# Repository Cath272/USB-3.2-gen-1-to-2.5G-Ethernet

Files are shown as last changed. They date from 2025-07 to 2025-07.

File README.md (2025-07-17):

# USB 3.2 gen 1 to 2.5Gb Ethernet
 2.5GbE to USB C using VL162 and RTL8156

 ## VL162

  - 4:2 10Gbps USB Type-C Data Switch

  - Low power consumption with 6mW active at device mode

 ## RTL8156BG 

  - Integrated 10/100/1000M/2.5G transceiver

  - Supports USB 3.0, 2.0, and 1.1

 ## TPS62420

 - 5V to 3.3V DC-DC (600mA)
 - 5V to 0.95V DC-DC (1A)

 ## W25Q16BVSSIG

 - 16Mbit SPI Flash  

 ## LX82405SP
 -2.5GbE Magnetics 
## PCB 
This board uses a 4 layer stackup with a  1.6mm thickness:

- POWER/SIGNAL

- GND
  
- GND
  
- POWER/SIGNAL

High Speed diferential lines need a refrence ground plane so internal planes are ground referance planes for the High speed USB lines

### Schematic:
Schematic
## PCB Screenshots

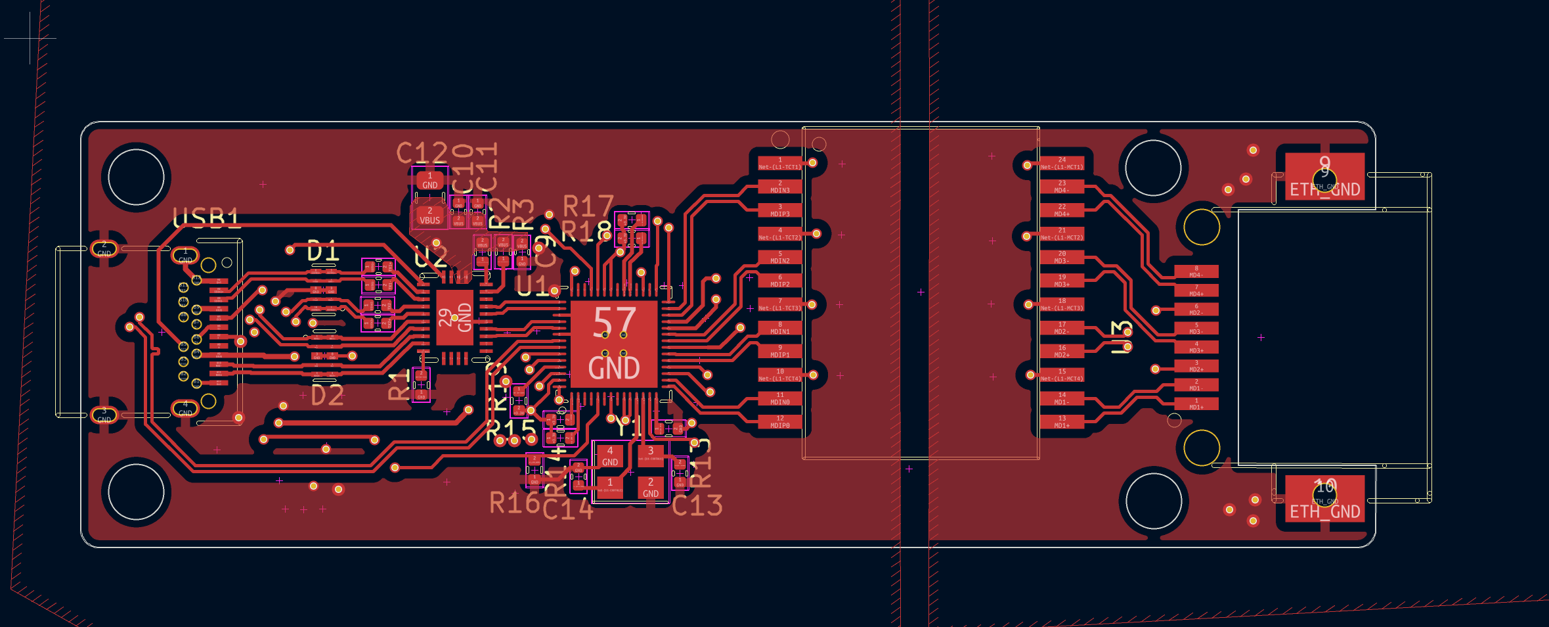
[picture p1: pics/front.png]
usb3ethfront

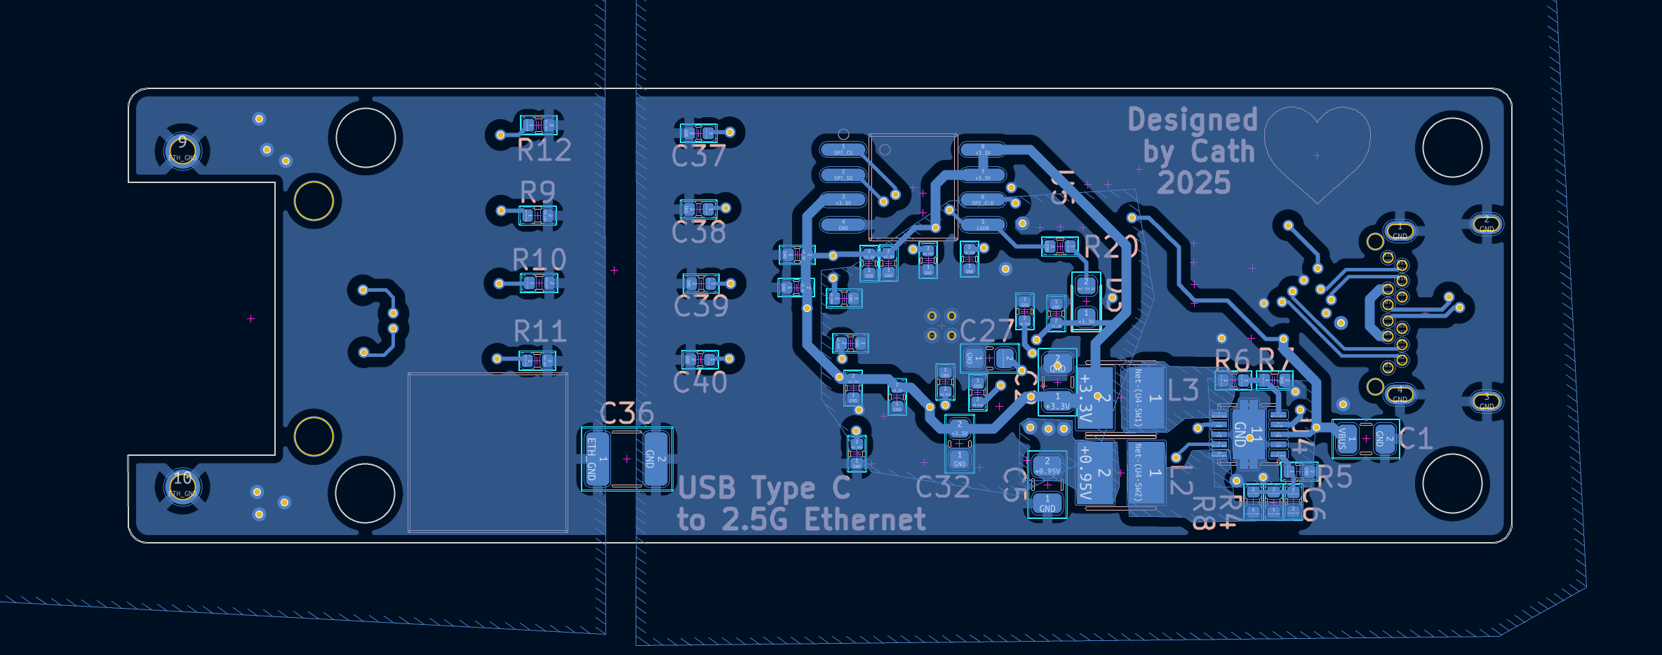
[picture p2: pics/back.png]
usb3ethback

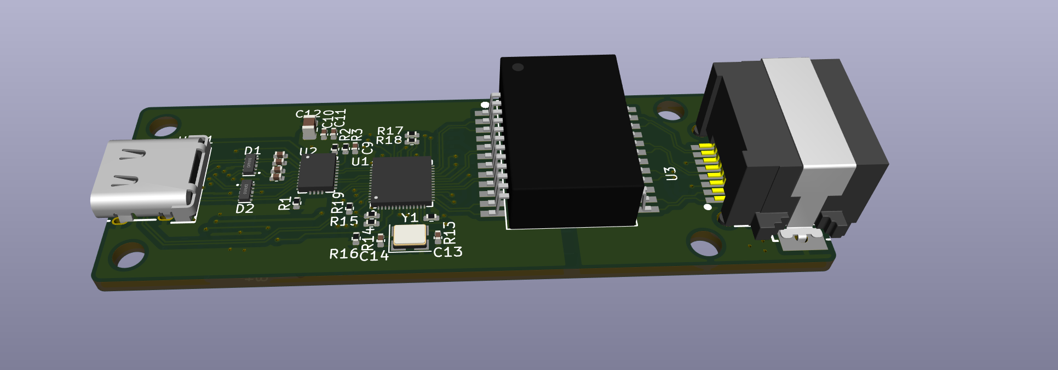
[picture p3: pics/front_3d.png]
usb3ethfront3d

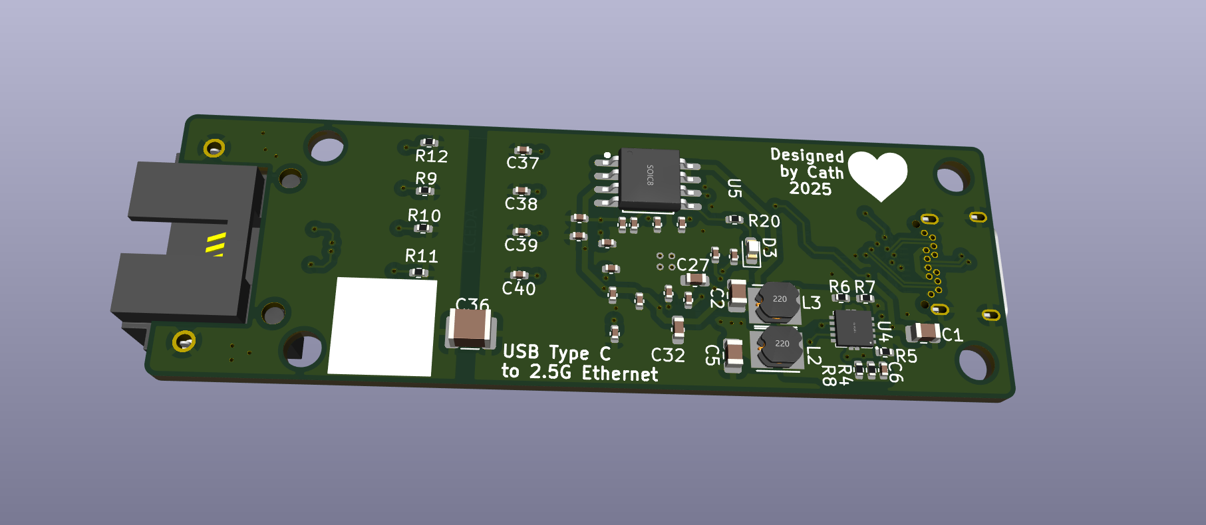
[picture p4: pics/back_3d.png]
usb3ethback3d


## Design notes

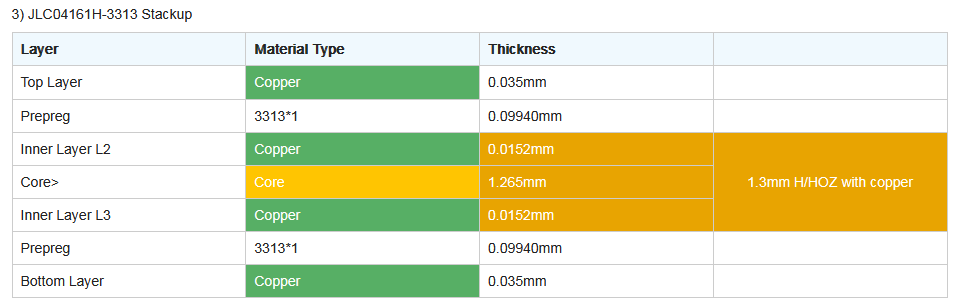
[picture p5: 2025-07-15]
Stackup.png

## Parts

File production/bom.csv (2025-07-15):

Designator | Footprint | Quantity | Value | LCSC Part #
C1, C12 | 0805 | 2 | 10uF
C10, C11, C16, C17, C18, C19, C20, C21, C22, C23, C24, C25, C26, C28, C29, C3, C30, C31, C37, C38, C39, C4, C40, C7, C8, C9 | 0402 | 26 | 100nF
C13, C14 | 0402 | 2 | 18pF
C2, C5 | 0805 | 2 | 22uF
C27, C32 | 0603 | 2 | 1uF
C36 | 1210 | 1 | 1nF 2kV
C6 | 0402 | 1 | 33pF
D1, D2 | DFN-10L_L2.5-W1.0-P0.50-BL | 2 | RCLAMP0524P-N | C316044
D3 | 0603 | 1 | LED
L1 | XFMR-SMD_HY602401 | 1 | HY602401 | C55685
L2, L3 | IND-SMD_L3.5-W3.0 | 2 | 2.2uH
R1 | 0402 | 1 | 124k
R10, R11, R12, R9 | 0402 | 4 | 75R
R13 | 0402 | 1 | 2.49K
R14, R15, R16, R17, R18, R19 | 0402 | 6 | 4.7K
R2, R3 | 0402 | 2 | 10k
R20 | 0402 | 1 | 220R
R4, R7 | 0402 | 2 | 180k
R5 | 0402 | 1 | 280k
R6 | 0402 | 1 | 910k
R8 | 0402 | 1 | 1.8M
U1 | QFN-56_L6.0-W6.0-P0.35--TL-EP4.7 | 1 | RTL8156BG-CG | C41376388
U2 | MQFN-28_L4.5-W3.5-P0.40-BL-EP | 1 | VL162 | C19270896
U3 | RJ45-SMD_HC-RJ45-055-7_1 | 1 | HC-RJ45-055-7 | C3000213
U4 | VSON-10_L3.0-W3.0-P0.50-TL-EP | 1 | TPS62420DRCR | C74233
U5 | SOIC-8_L5.3-W5.3-P1.27-LS8.0-BL | 1 | W25Q16BVSSIG
USB1 | USB-C-SMD_TYPEC-324-BCP24 | 1 | TYPEC-324-BCP24 | C2835314
Y1 | Crystal_SMD_3225-4Pin_3.2x2.5mm | 1 | 25Mhz

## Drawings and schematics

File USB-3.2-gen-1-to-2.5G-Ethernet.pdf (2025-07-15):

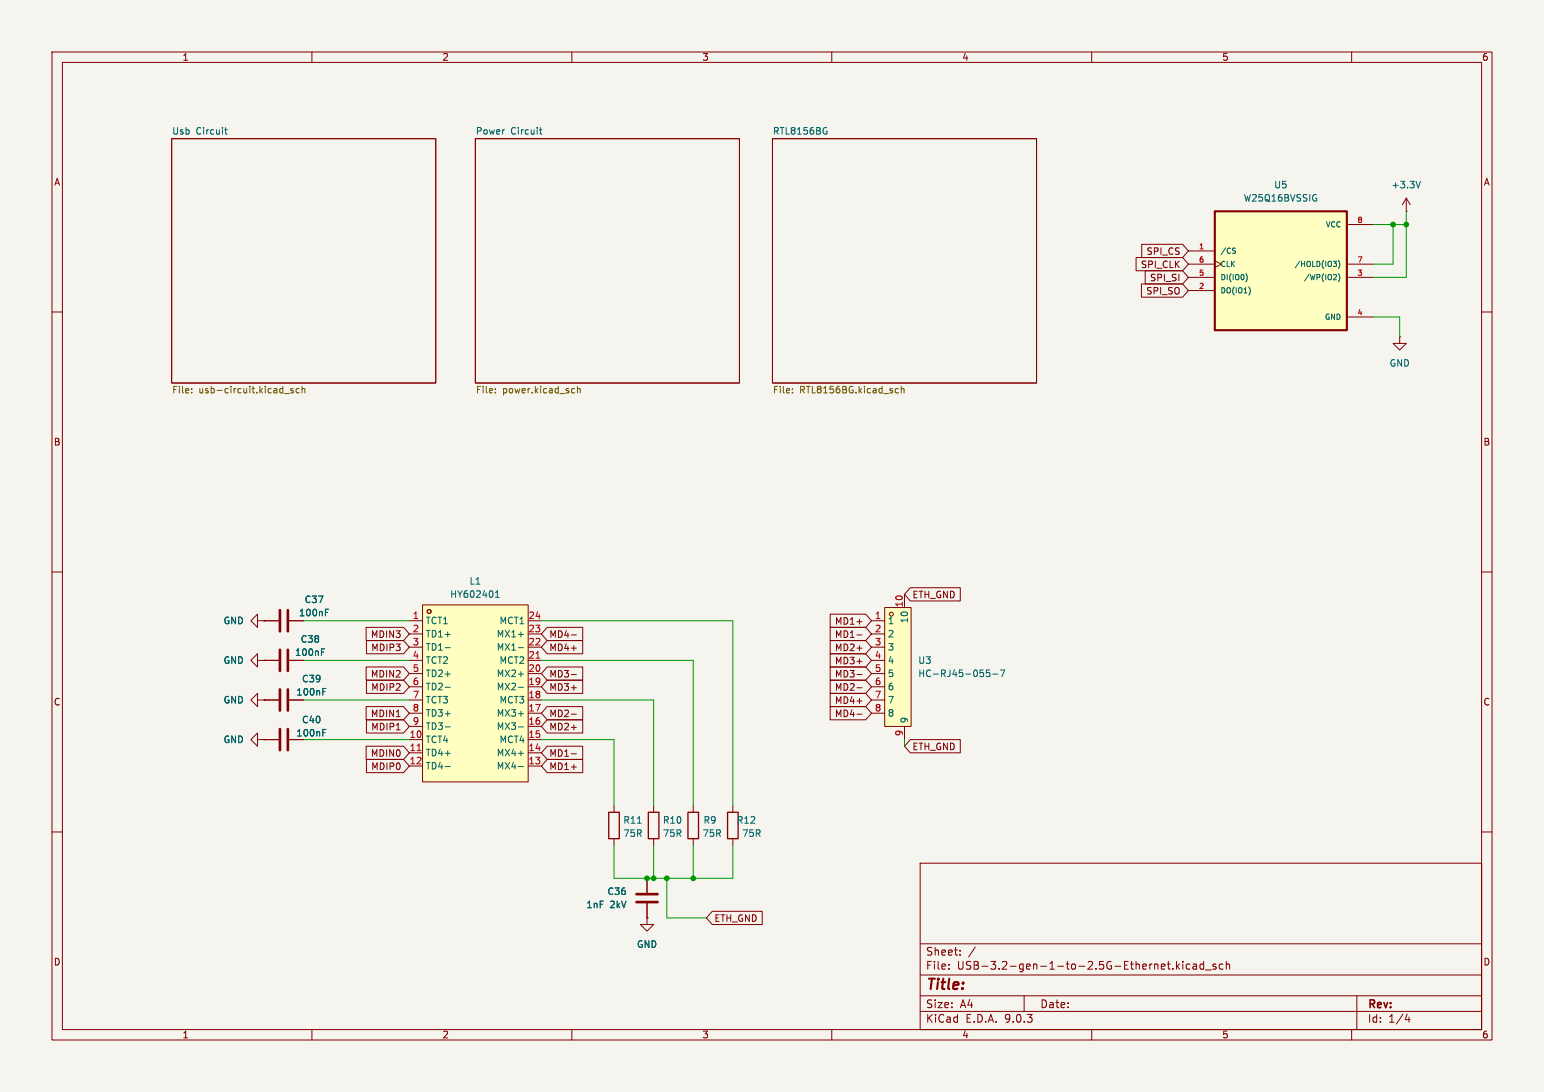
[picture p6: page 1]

Id: 1/4 Title: File: USB-3.2-gen-1-to-2.5G-Ethernet.kicad_sch Sheet: /

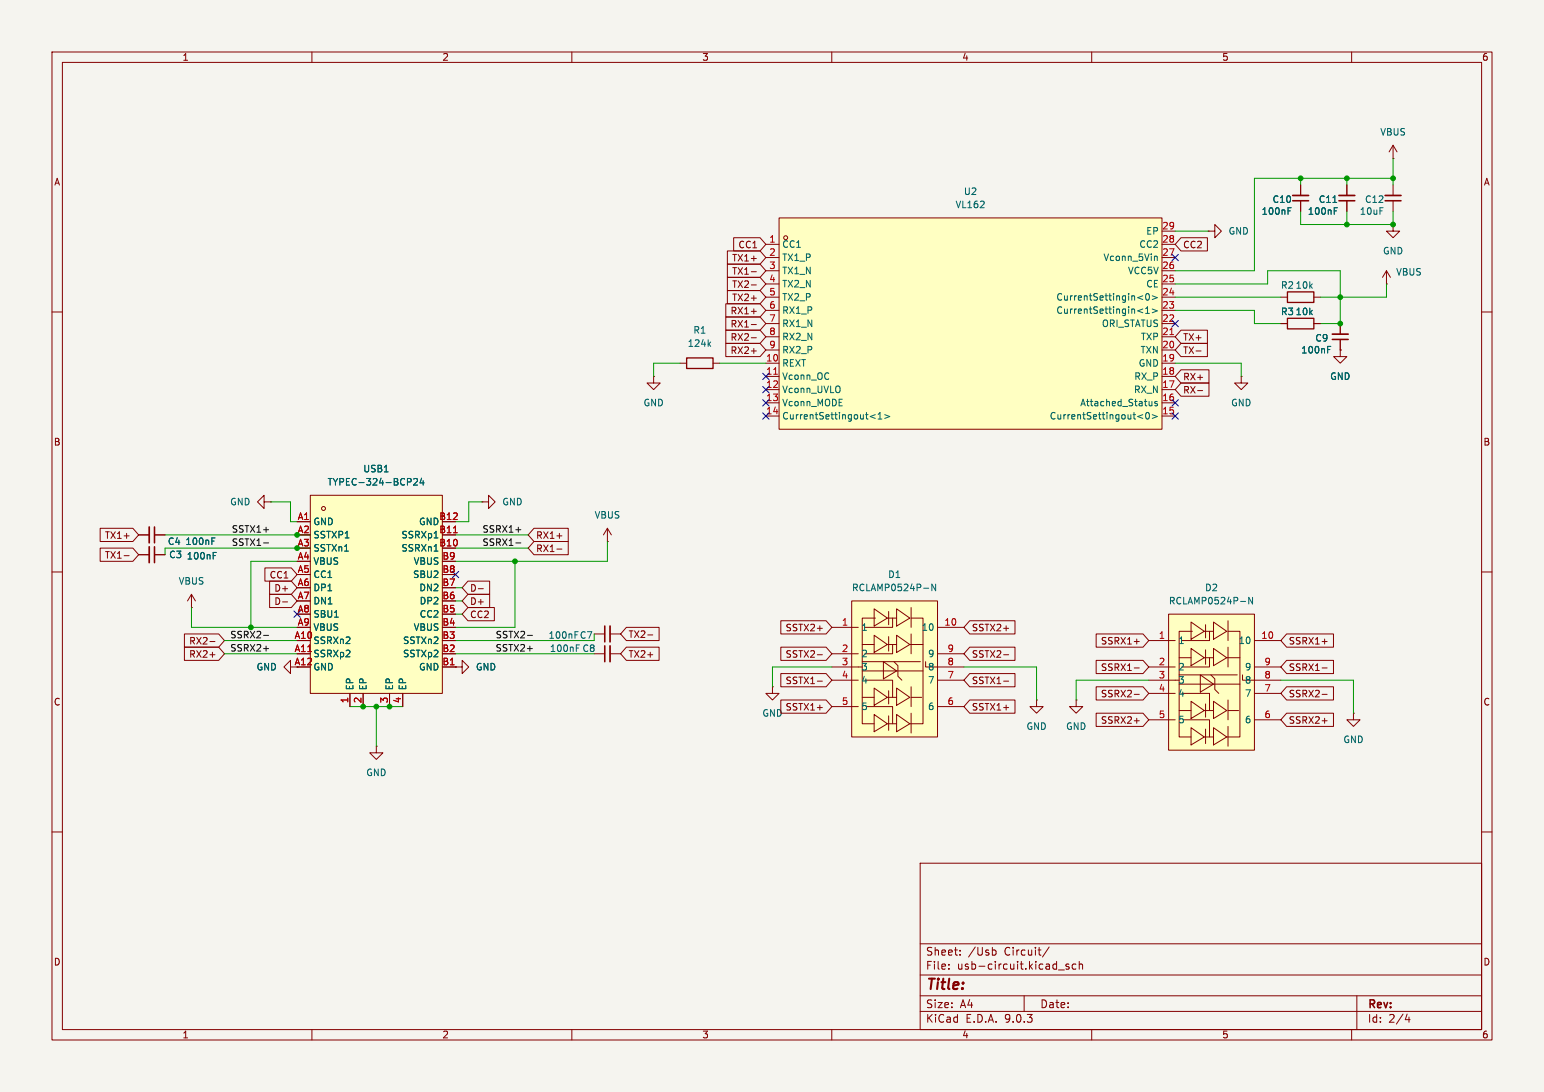
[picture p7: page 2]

4 GNDB12 SSRXp1 B11 SSRXn1 B10 VBUS B9 SBU2 B8 DN2 B7 DP2 B6 CC2 B5 VBUS B4 SSTXn2 B3 SSTXp2 B2 GND B1 C4 100nF C3 100nF R3 10k GND

4 GNDB12 SSRXp1 B11 SSRXn1 B10 VBUS B9 SBU2 B8 DN2 B7 DP2 B6 CC2 B5 VBUS B4 SSTXn2 B3 SSTXp2 B2 GND B1 USB1 TYPEC-324-BCP24 R1

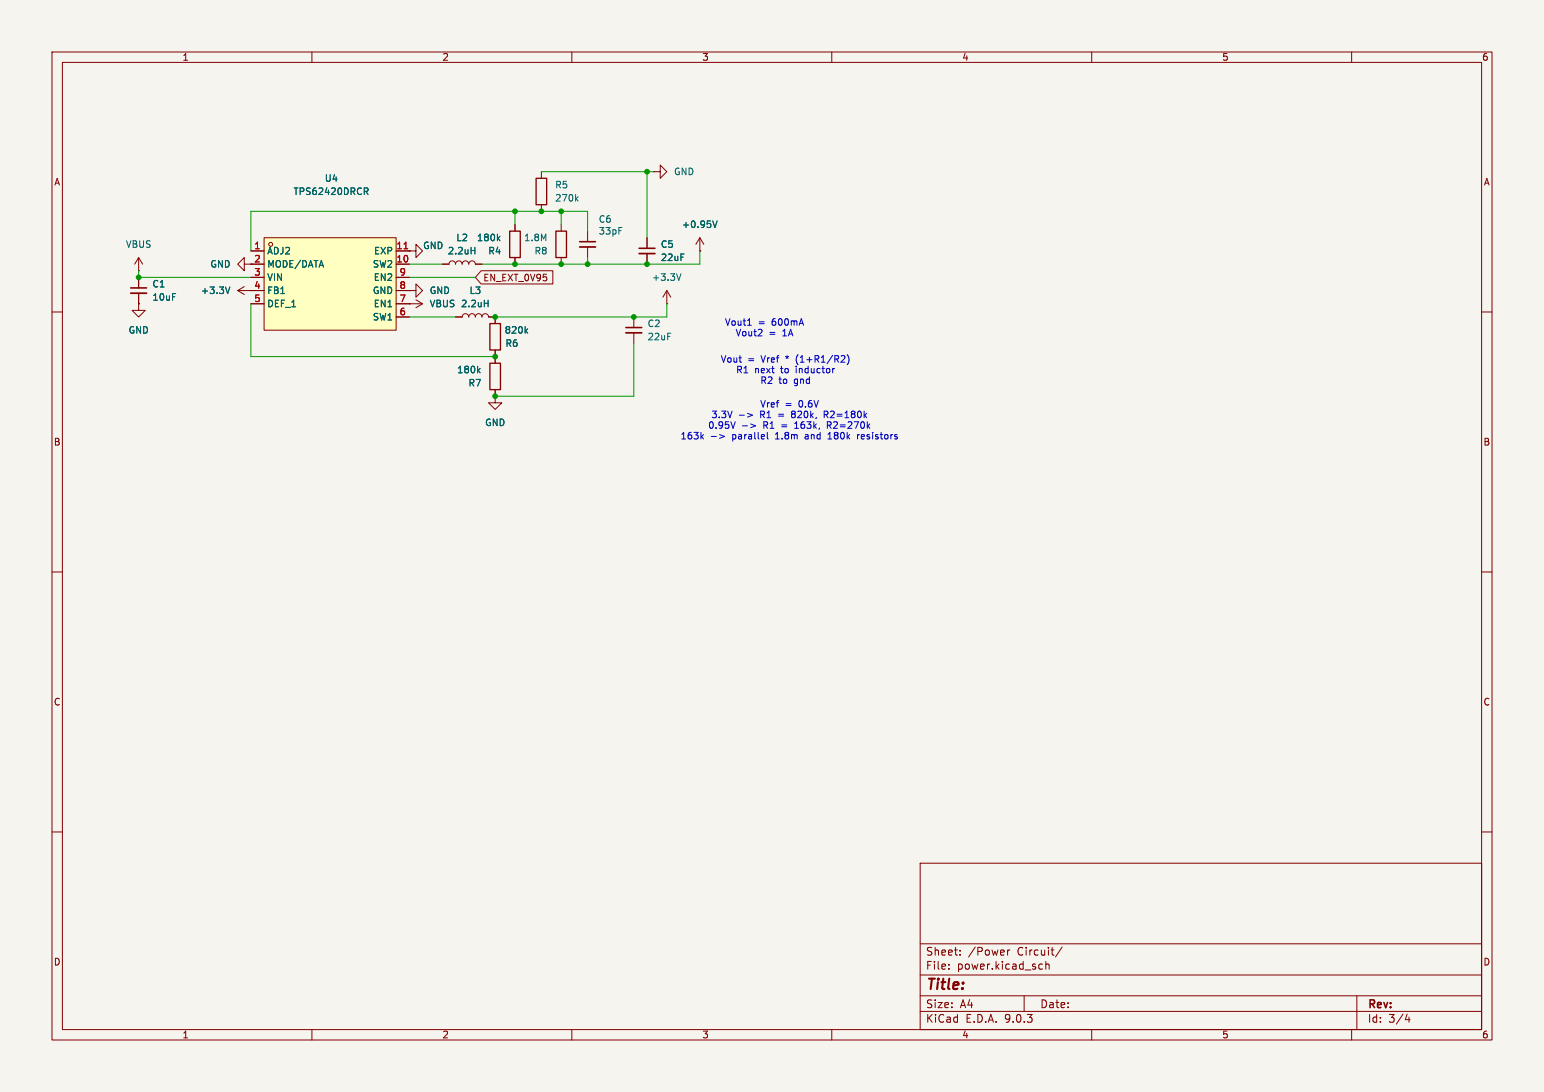
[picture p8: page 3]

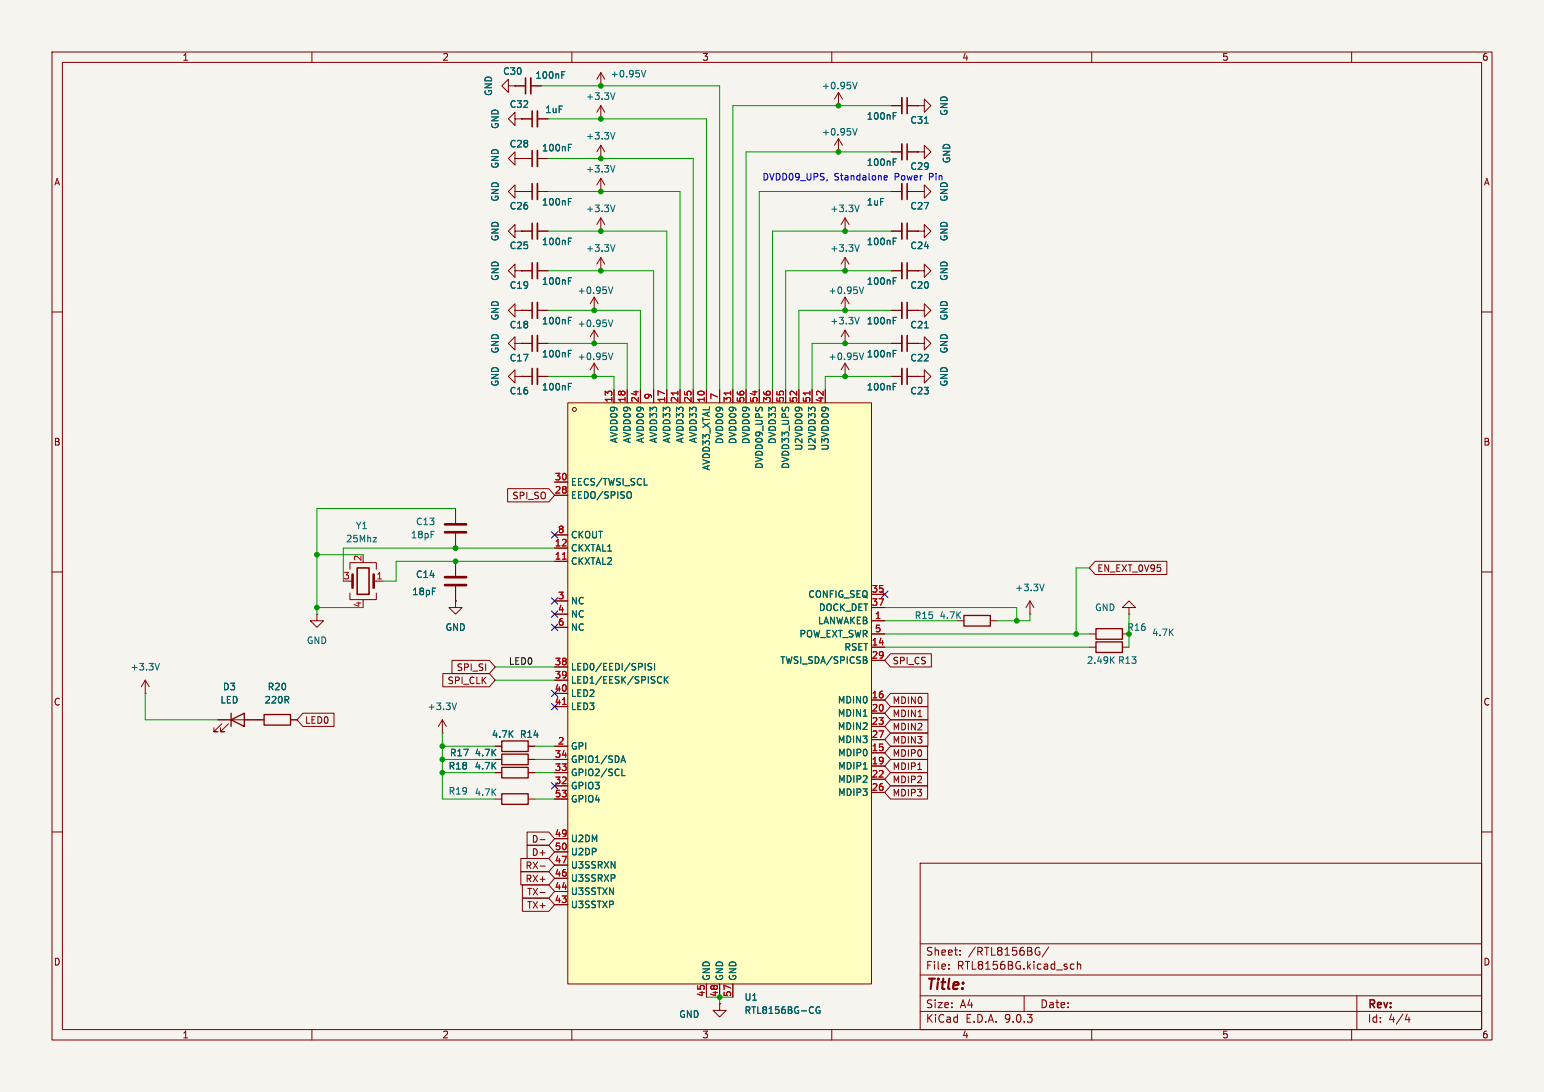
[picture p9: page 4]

Id: 4/4 Title: File: RTL8156BG.kicad_sch Sheet: /RTL8156BG/ GND

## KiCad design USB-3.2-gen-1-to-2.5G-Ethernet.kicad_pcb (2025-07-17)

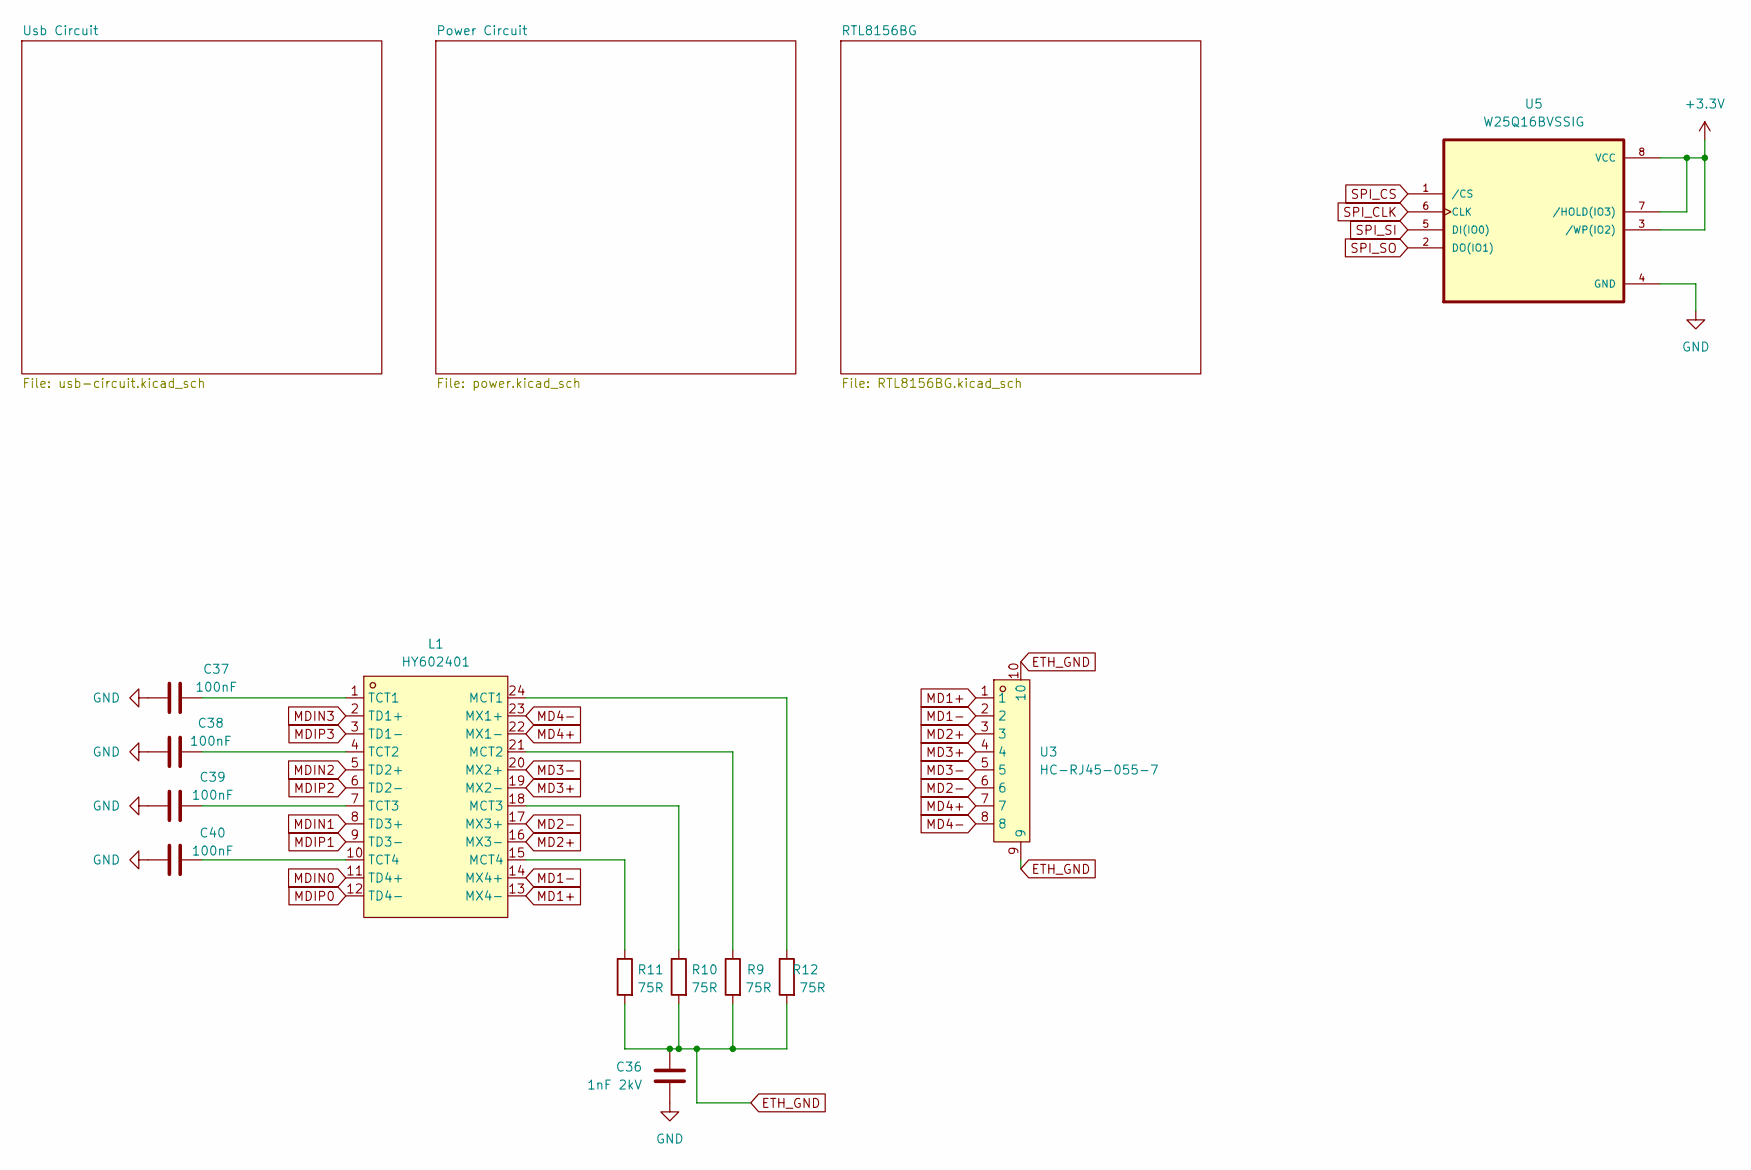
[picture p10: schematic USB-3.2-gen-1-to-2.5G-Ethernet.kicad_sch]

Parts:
C36: 1nF 2kV; C_1210_3225Metric
C37, C38, C39, C40: 100nF; C_0402_1005Metric
L1: HY602401; XFMR-SMD_HY602401; LCSC Part C55685
R9, R10, R11, R12: 75R; R_0402_1005Metric
U3: HC-RJ45-055-7; RJ45-SMD_HC-RJ45-055-7_1; LCSC Part C3000213
U5: W25Q16BVSSIG; SOIC-8_L5.3-W5.3-P1.27-LS8.0-BL; PARTREV F

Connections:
+3.3V: U5.3 (/WP(IO2)), U5.7 (/HOLD(IO3)), U5.8 (VCC); also elsewhere on the board
ETH_GND: C36.1, R9.2, R10.2, R11.2, R12.2, U3.9, U3.10
GND: C36.2, C37.2, C38.2, C39.2, C40.2, U5.4 (GND); also elsewhere on the board
LED0: U5.5 (DI(IO0)); also elsewhere on the board
MD1+: L1.13 (MX4-), U3.1
MD1-: L1.14 (MX4+), U3.2
MD2+: L1.16 (MX3-), U3.3
MD2-: L1.17 (MX3+), U3.6
MD3+: L1.19 (MX2-), U3.4
MD3-: L1.20 (MX2+), U3.5
MD4+: L1.22 (MX1-), U3.7
MD4-: L1.23 (MX1+), U3.8
MDIN0: L1.11 (TD4+); also elsewhere on the board
MDIN1: L1.8 (TD3+); also elsewhere on the board
MDIN2: L1.5 (TD2+); also elsewhere on the board
MDIN3: L1.2 (TD1+); also elsewhere on the board
MDIP0: L1.12 (TD4-); also elsewhere on the board
MDIP1: L1.9 (TD3-); also elsewhere on the board
MDIP2: L1.6 (TD2-); also elsewhere on the board
MDIP3: L1.3 (TD1-); also elsewhere on the board
unnamed: L1.24 (MCT1), R12.1
unnamed: L1.21 (MCT2), R9.1
unnamed: L1.18 (MCT3), R10.1
unnamed: L1.15 (MCT4), R11.1
unnamed: C37.1, L1.1 (TCT1)
unnamed: C38.1, L1.4 (TCT2)
unnamed: C39.1, L1.7 (TCT3)
unnamed: C40.1, L1.10 (TCT4)
SPI_CLK: U5.6 (CLK); also elsewhere on the board
SPI_CS: U5.1 (/CS); also elsewhere on the board
SPI_SO: U5.2 (DO(IO1)); also elsewhere on the board

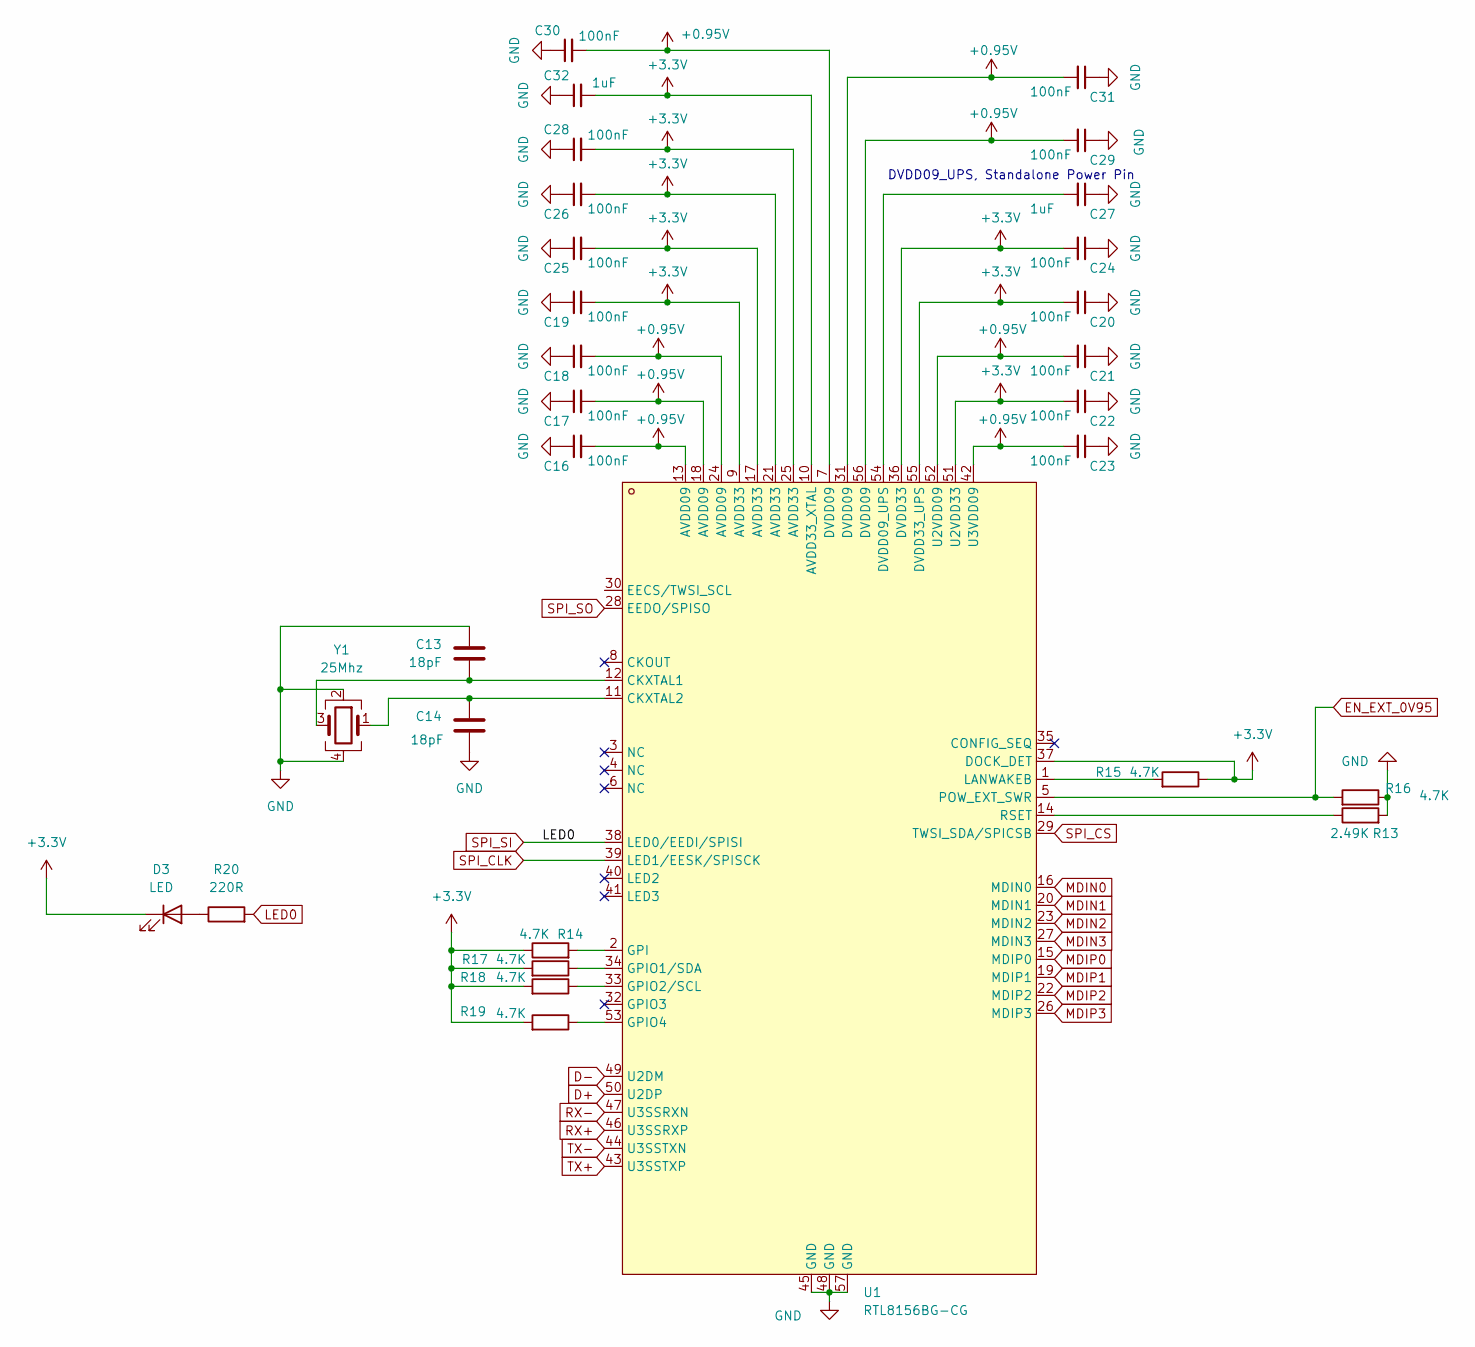
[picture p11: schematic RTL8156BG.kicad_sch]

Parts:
C13, C14: 18pF; C_0402_1005Metric
C16, C17, C18, C19, C20, C21, C22, C23, C24, C25, C26, C28, C29, C30, C31: 100nF; C_0402_1005Metric
C27, C32: 1uF; C_0603_1608Metric
D3: LED; LED_0603_1608Metric
R13: 2.49K; R_0402_1005Metric
R14, R15, R16, R17, R18, R19: 4.7K; R_0402_1005Metric
R20: 220R; R_0402_1005Metric
U1: RTL8156BG-CG; QFN-56_L6.0-W6.0-P0.35--TL-EP4.7; LCSC Part C41376388
Y1: 25Mhz; Crystal_SMD_3225-4Pin_3.2x2.5mm

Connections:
+0.95V: C16.2, C17.2, C18.2, C21.2, C23.2, C29.2, C30.2, C31.2, U1.7 (DVDD09), U1.13 (AVDD09), U1.18 (AVDD09), U1.24 (AVDD09), U1.31 (DVDD09), U1.42 (U3VDD09), U1.52 (U2VDD09), U1.56 (DVDD09); also elsewhere on the board
+3.3V: C19.2, C20.2, C22.2, C24.2, C25.2, C26.2, C28.2, C32.2, D3.1 (K), R14.1, R15.1, R17.2, R18.2, R19.2, U1.9 (AVDD33), U1.10 (AVDD33_XTAL), U1.17 (AVDD33), U1.21 (AVDD33), U1.25 (AVDD33), U1.36 (DVDD33), U1.37 (DOCK_DET), U1.51 (U2VDD33), U1.55 (DVDD33_UPS); also elsewhere on the board
D+: U1.50 (U2DP); also elsewhere on the board
D-: U1.49 (U2DM); also elsewhere on the board
EN_EXT_0V95: R16.2, U1.5 (POW_EXT_SWR); also elsewhere on the board
GND: C13.1, C14.2, C16.1, C17.1, C18.1, C19.1, C20.1, C21.1, C22.1, C23.1, C24.1, C25.1, C26.1, C27.1, C28.1, C29.1, C30.1, C31.1, C32.1, R13.2, R16.1, U1.45 (GND), U1.48 (GND), U1.57 (GND), Y1.2, Y1.4; also elsewhere on the board
LED0: R20.2, U1.38 (LED0/EEDI/SPISI); also elsewhere on the board
MDIN0: U1.16 (MDIN0); also elsewhere on the board
MDIN1: U1.20 (MDIN1); also elsewhere on the board
MDIN2: U1.23 (MDIN2); also elsewhere on the board
MDIN3: U1.27 (MDIN3); also elsewhere on the board
MDIP0: U1.15 (MDIP0); also elsewhere on the board
MDIP1: U1.19 (MDIP1); also elsewhere on the board
MDIP2: U1.22 (MDIP2); also elsewhere on the board
MDIP3: U1.26 (MDIP3); also elsewhere on the board
unnamed: D3.2 (A), R20.1
unnamed: C13.2, U1.12 (CKXTAL1), Y1.3
unnamed: C14.1, U1.11 (CKXTAL2), Y1.1
unnamed: C27.2, U1.54 (DVDD09_UPS)
unnamed: R14.2, U1.2 (GPI)
unnamed: R17.1, U1.34 (GPIO1/SDA)
unnamed: R18.1, U1.33 (GPIO2/SCL)
unnamed: R19.1, U1.53 (GPIO4)
unnamed: R15.2, U1.1 (LANWAKEB)
unnamed: R13.1, U1.14 (RSET)
RX+: U1.46 (U3SSRXP); also elsewhere on the board
RX-: U1.47 (U3SSRXN); also elsewhere on the board
SPI_CLK: U1.39 (LED1/EESK/SPISCK); also elsewhere on the board
SPI_CS: U1.29 (TWSI_SDA/SPICSB); also elsewhere on the board
SPI_SO: U1.28 (EEDO/SPISO); also elsewhere on the board
TX+: U1.43 (U3SSTXP); also elsewhere on the board
TX-: U1.44 (U3SSTXN); also elsewhere on the board

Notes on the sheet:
DVDD09_UPS, Standalone Power Pin

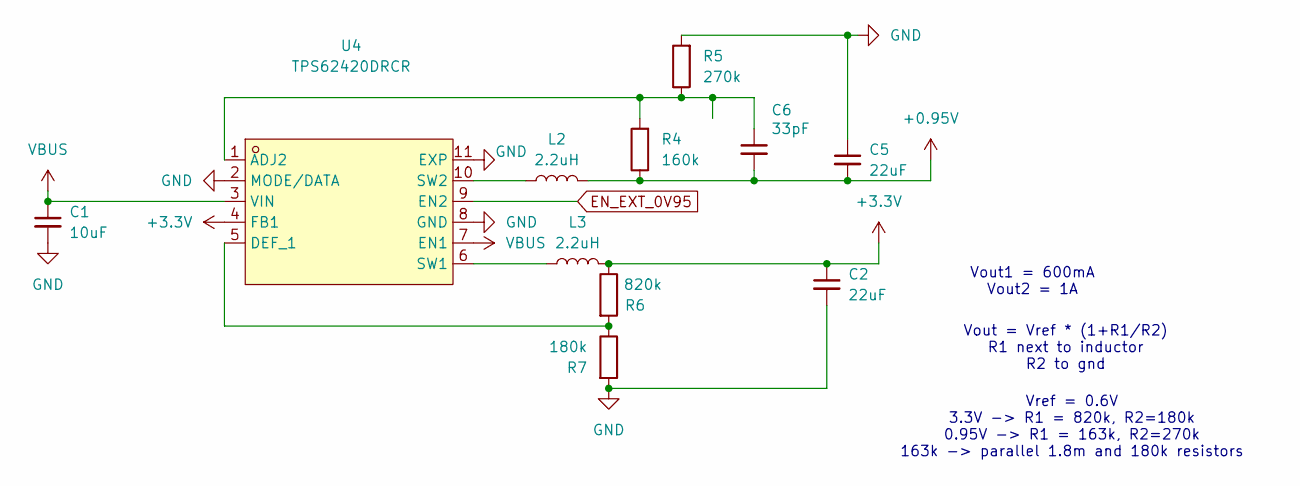
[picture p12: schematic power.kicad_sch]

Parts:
C1: 10uF; C_0805_2012Metric
C2, C5: 22uF; C_0805_2012Metric
C6: 33pF; C_0402_1005Metric
L2, L3: 2.2uH; IND-SMD_L3.5-W3.0
R4: 160k; R_0402_1005Metric
R5: 270k; R_0402_1005Metric
R6: 820k; R_0402_1005Metric
R7: 180k; R_0402_1005Metric
U4: TPS62420DRCR; VSON-10_L3.0-W3.0-P0.50-TL-EP; LCSC Part C74233

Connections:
+0.95V: C5.2, C6.2, L2.2, R4.1; also elsewhere on the board
+3.3V: C2.1, L3.2, R6.1, U4.4 (FB1); also elsewhere on the board
EN_EXT_0V95: U4.9 (EN2); also elsewhere on the board
GND: C1.2, C2.2, C5.1, R5.2, R7.2, U4.2 (MODE/DATA), U4.8 (GND), U4.11 (EXP); also elsewhere on the board
unnamed: C6.1, R4.2, R5.1, U4.1 (ADJ2)
unnamed: R6.2, R7.1, U4.5 (DEF_1)
unnamed: L3.1, U4.6 (SW1)
unnamed: L2.1, U4.10 (SW2)
VBUS: C1.1, U4.3 (VIN), U4.7 (EN1); also elsewhere on the board

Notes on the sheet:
Vref = 0.6V 3.3V -> R1 = 820k, R2=180k 0.95V -> R1 = 163k, R2=270k 163k -> parallel 1.8m and 180k resistors
Vout = Vref * (1+R1/R2) R1 next to inductor R2 to gnd
Vout1 = 600mA Vout2 = 1A

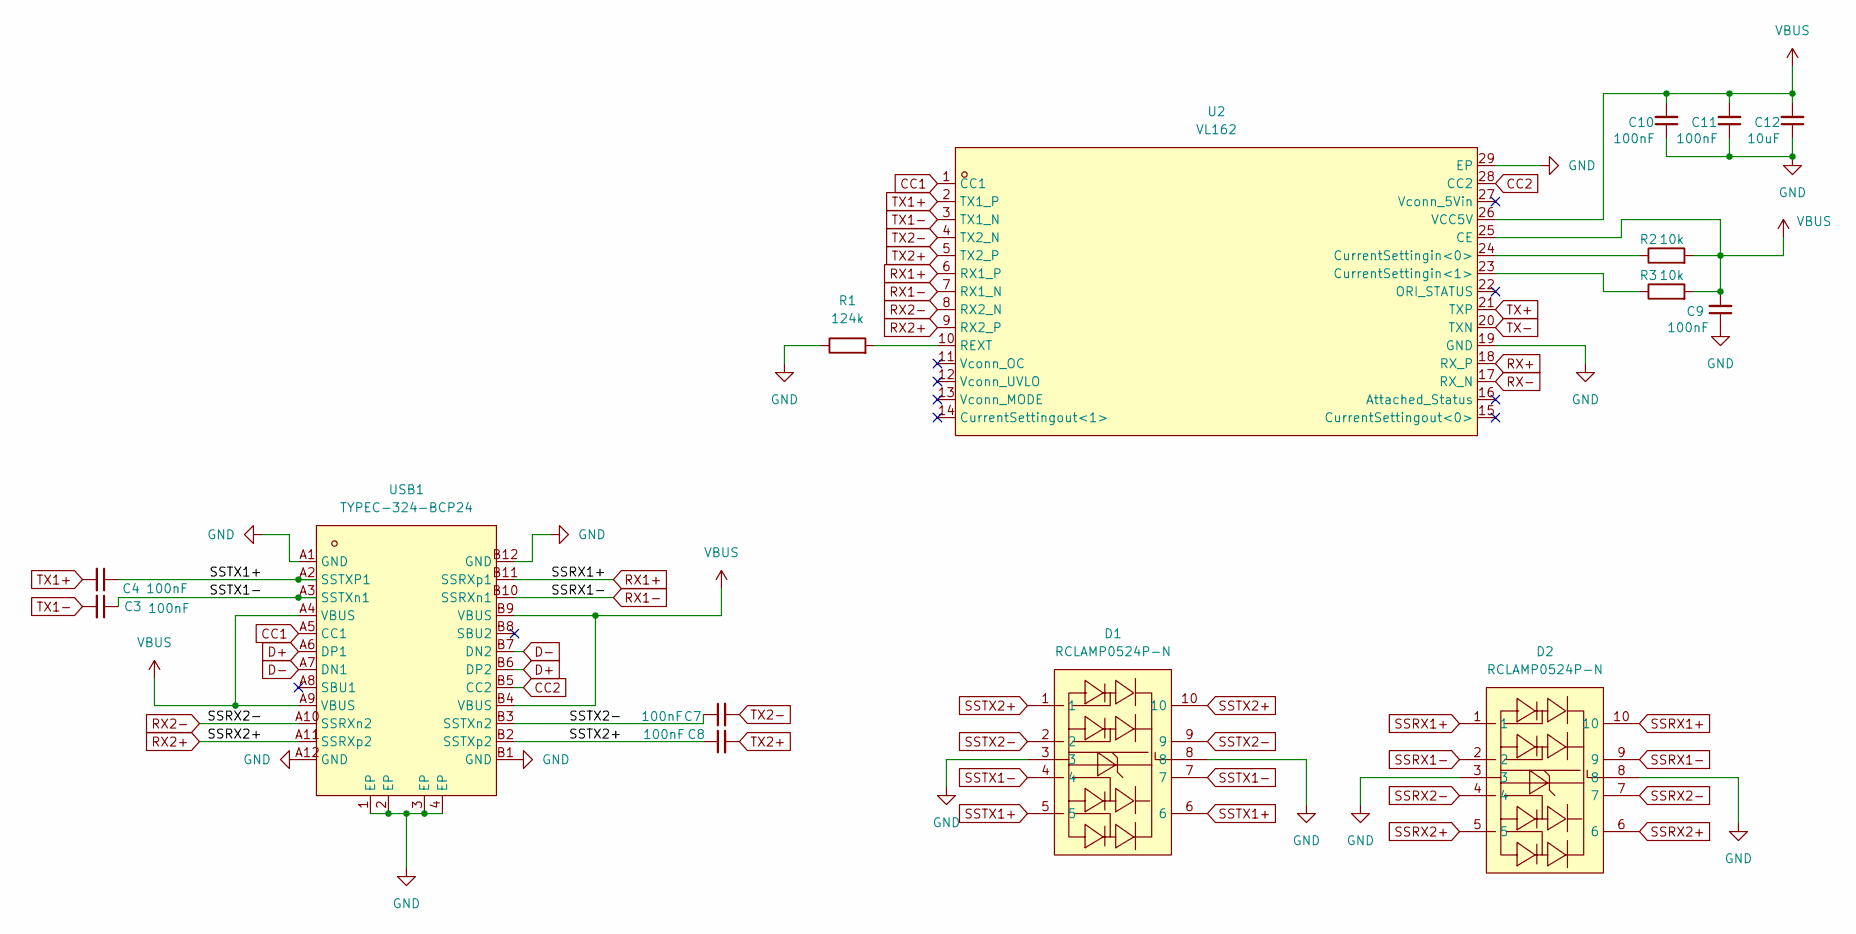
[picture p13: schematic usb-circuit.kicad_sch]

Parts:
C3, C4, C7, C8, C9, C10, C11: 100nF; C_0402_1005Metric
C12: 10uF; C_0805_2012Metric
D1, D2: RCLAMP0524P-N; DFN-10L_L2.5-W1.0-P0.50-BL; LCSC Part C316044
R1: 124k; R_0402_1005Metric
R2, R3: 10k; R_0402_1005Metric
U2: VL162; MQFN-28_L4.5-W3.5-P0.40-BL-EP; LCSC Part C19270896
USB1: TYPEC-324-BCP24; USB-C-SMD_TYPEC-324-BCP24; LCSC Part C2835314

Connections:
CC1: U2.1 (CC1), USB1.A5 (CC1)
CC2: U2.28 (CC2), USB1.B5 (CC2)
D+: USB1.A6 (DP1), USB1.B6 (DP2); also elsewhere on the board
D-: USB1.A7 (DN1), USB1.B7 (DN2); also elsewhere on the board
GND: C9.1, C10.1, C11.1, C12.1, D1.3, D1.8, D2.3, D2.8, R1.1, U2.19 (GND), U2.29 (EP), USB1.1 (EP), USB1.2 (EP), USB1.3 (EP), USB1.4 (EP), USB1.A1 (GND), USB1.A12 (GND), USB1.B1 (GND), USB1.B12 (GND); also elsewhere on the board
unnamed: R2.1, U2.24 (CurrentSettingin<0>)
unnamed: R3.1, U2.23 (CurrentSettingin<1>)
unnamed: R1.2, U2.10 (REXT)
RX1+: D2.1, D2.10, U2.6 (RX1_P), USB1.B11 (SSRXp1)
RX1-: D2.2, D2.9, U2.7 (RX1_N), USB1.B10 (SSRXn1)
RX2+: D2.5, D2.6, U2.9 (RX2_P), USB1.A11 (SSRXp2)
RX2-: D2.4, D2.7, U2.8 (RX2_N), USB1.A10 (SSRXn2)
RX+: U2.18 (RX_P); also elsewhere on the board
RX-: U2.17 (RX_N); also elsewhere on the board
SSTX1+: C4.1, D1.5, D1.6, USB1.A2 (SSTXP1)
SSTX1-: C3.1, D1.4, D1.7, USB1.A3 (SSTXn1)
SSTX2+: C8.1, D1.1, D1.10, USB1.B2 (SSTXp2)
SSTX2-: C7.1, D1.2, D1.9, USB1.B3 (SSTXn2)
TX1+: C4.2, U2.2 (TX1_P)
TX1-: C3.2, U2.3 (TX1_N)
TX2+: C8.2, U2.5 (TX2_P)
TX2-: C7.2, U2.4 (TX2_N)
TX+: U2.21 (TXP); also elsewhere on the board
TX-: U2.20 (TXN); also elsewhere on the board
VBUS: C9.2, C10.2, C11.2, C12.2, R2.2, R3.2, U2.25 (CE), U2.26 (VCC5V), USB1.A4 (VBUS), USB1.A9 (VBUS), USB1.B4 (VBUS), USB1.B9 (VBUS); also elsewhere on the board

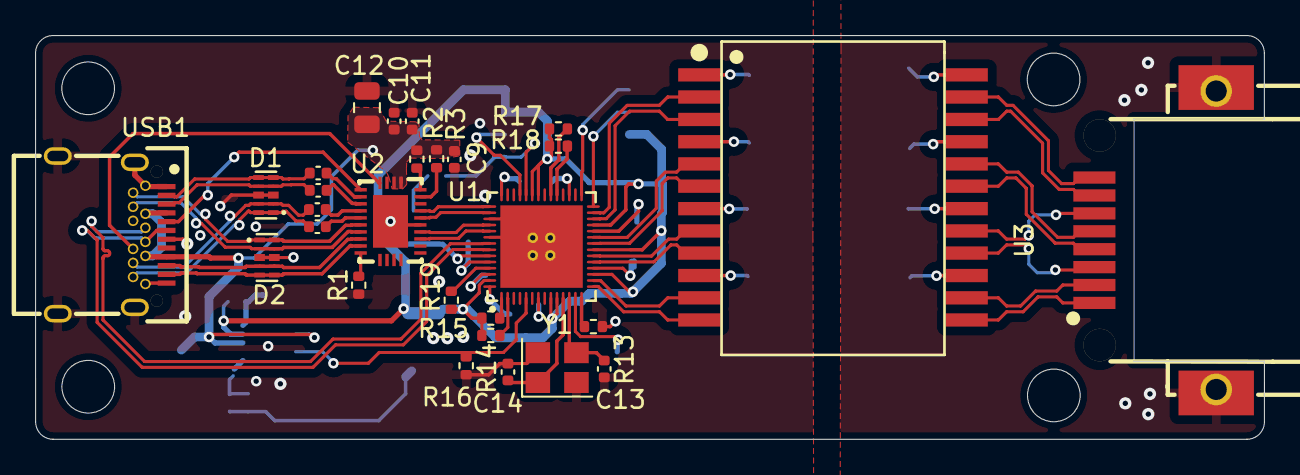
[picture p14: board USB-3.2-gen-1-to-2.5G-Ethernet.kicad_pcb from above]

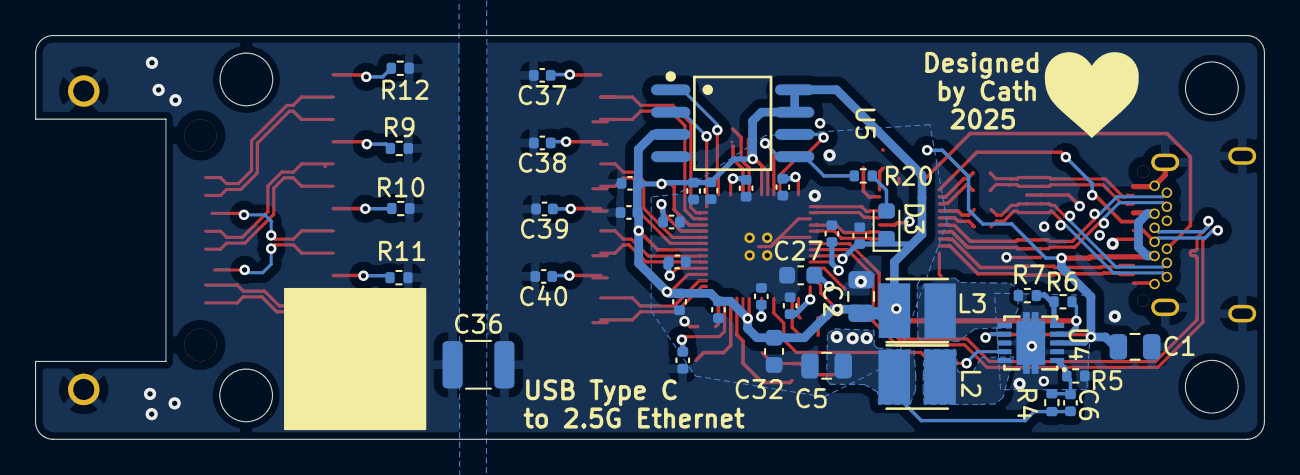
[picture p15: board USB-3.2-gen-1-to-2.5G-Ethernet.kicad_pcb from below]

Board: 4 copper layers, 70.0 x 23.0 mm, 68 parts (40 on the bottom side), 71 nets.
